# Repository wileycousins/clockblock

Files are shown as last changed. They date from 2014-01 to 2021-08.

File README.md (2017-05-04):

# clockblock

clockblock

An LED clock in a block of wood. This repository contains the electronics design files and firmware source code.

## firmware

Firmware is written in C++ and compiled in GCC 4.6.2 with AVR modifications. If you're using a Mac, install [CrossPack for AVR 2013-02-12](http://www.obdev.at/products/crosspack/index.html) for all the necessary tools. Otherwise, do some Googling.

The clockblock uses an ATTiny167 with 16KB of flash and 512B of RAM. At compilation, the application takes about 6KB of program and 30B of RAM. Currently firmware must be flashed onto the board with an ISP, but hardware supports USB bootloading*. An Arduino-compatible bootloader is in the works.

*v1.0 hardware has a trace that must be cut and replaced with a capacitor for this to work. See [issue #6](https://github.com/wileycousins/clockblock/issues/6).

## hardware

The PCBs are designed in [KiCad](https://launchpad.net/kicad). There are gerber files in the repo, but your best bet is to generate them yourself from KiCad. Components are from [these libraries](https://github.com/mcous/kicad-lib), but you shouldn't have to install them to view the schematic and board files if you don't want to.

The boards are almost entirely surface mount, so solder-paste and a reflow tool of some sort (hot-air gun, toaster, hot-plate) are recommended. If anyone manages this with just an iron, I'd love to see pictures, because that's awesome. Shameless self promotion: I know about this pretty good [toaster oven control board for solder reflow](https://github.com/mcous/reflow).

[clockblock-image]: https://cloud.githubusercontent.com/assets/2963448/25712589/0aaff954-30c0-11e7-9aac-50ed0ab61022.jpg

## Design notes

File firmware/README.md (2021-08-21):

# firmware

## setup

### Arduino (one time setup)
Make sure you have `Arduino.app` installed in the usual place.

You'll need a special Board for Arduino. Add `http://drazzy.com/package_drazzy.com_index.json` to the `Additional Boards Manager URLs: ` in the Preferences in Arduino.

You'll need to setup your Arduino Uno for `ArduinoISP`. Select `ArduinoISP` from the `File > Examples > ArduinoISP`. Upload this sketch to the Uno.

Now wire the AVR ISP board into the appropriate pins on the Uno. Also, very important! Put a 10µf capacitor between ground and reset. Make sure to put the ground of the capacitor in the ground (the short leg).

### .env

This is being tracked in git which is debatable, but we should have the same env at this point and nothing sensitive is in here. But this is how the .env was made just for reference:

```bash
# Add the Arduino avr stuff to your path
echo "export PATH=/Applications/Arduino.app/Contents/Java/hardware/tools/avr/bin:\$PATH" >> .env

# make sure Arduino Uno is plugged in and setup for ArduinoISP
echo "export SERIAL_PORT=\$(ls /dev/cu.usb*)" >> .env
```

Follow dmg package install steps

## build

```bash
source .env
cd src
make
```

## flash

```bash
# make sure you env is all good to go
source ../.env
make test
# assuming the test comes back all good.
make flash
```

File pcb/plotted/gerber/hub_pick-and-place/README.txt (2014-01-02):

clockblock v1.0 hub and usb boards
Prepared by Michael Cousins
michael@wileycousins.com
(281) 210-6984

This panel consists of the two boards in our product with surface mount components. We will handle de-panellization. 

Requested specs:
  * ENIG finish
  * 0.062", 1 oz copper
  * White soldermask
  * Silkscreen on both sides
  * Red silkscreen if possible, otherwise black silkscreen

File summary:
Gerbers:
  * clockblock-hub-B_Cu.gbl      - bottom copper
  * clockblock-hub-B_Mask.gbs    - botton soldermask
  * clockblock-hub-B_SilkS.gbo   - bottom silkscreen
  * clockblock-hub-Edge_Cuts.gbr - board outline
  * clockblock-hub-F_Cu.gtl      - top copper
  * clockblock-hub-F_Mask.gts    - top soldermask
  * clockblock-hub-F_Paste.gtp   - top solderpaste
  * clockblock-hub-F_SilkS.gto   - top silkscreen
Excellon drill files (inches, 2:4 precision, no zero suppression):
  * clockblock-hub-NPTH.drl - drill file for non-plated though holes
  * clockblock-hub.drl      - drill file for plated through holes

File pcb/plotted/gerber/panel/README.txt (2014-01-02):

clockblock v0.2 arms panel
Prepared by Michael Cousins
michael@wileycousins.com

This panel is 4.8" x 4.2" and divided by v-scoring into 48 0.6" x 0.7" boards. The panel should have 7 evenly-spaced vertical v-scores and 5 evenly-spaced horizontal v-scores. Score lines are indicated in the board outline file.

Requested specs:
  * ENIG finish
  * 0.062", 1 oz copper
  * White soldermask
  * Silkscreen on top, none on bottom
  * Red silkscreen if possible, otherwise black silkscreen

File summary:
Gerbers:
  * clockblock-arms-B_Cu.gbl      - bottom copper
  * clockblock-arms-B_Mask.gbs    - botton soldermask
  * clockblock-arms-Edge_Cuts.gbr - board outline and scoring indication
  * clockblock-arms-F_Cu.gtl      - top copper
  * clockblock-arms-F_Mask.gts    - top soldermask
  * clockblock-arms-F_SilkS.gto   - top silkscreen
Excellon drill files (inches, 2:4 precision, no zero suppression):
  * clockblock-arms.drl - drill file for plated through holes

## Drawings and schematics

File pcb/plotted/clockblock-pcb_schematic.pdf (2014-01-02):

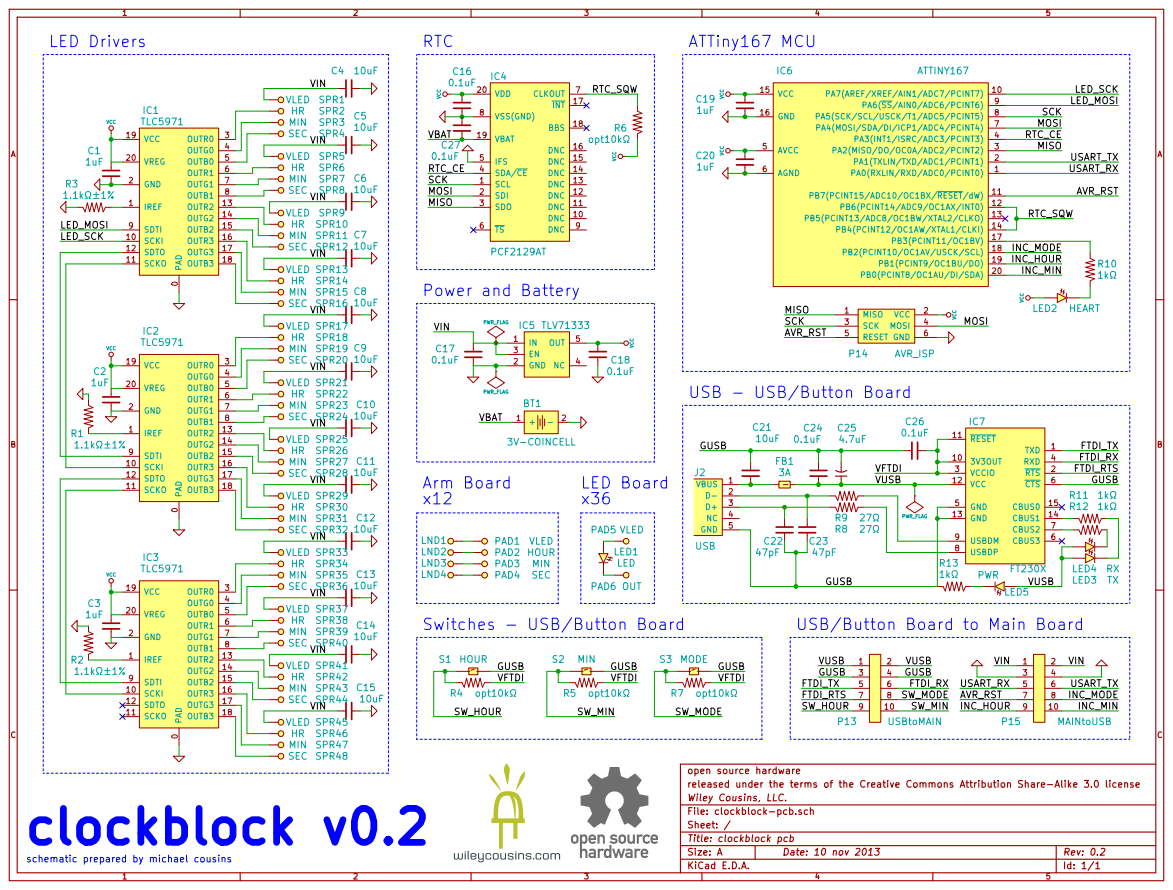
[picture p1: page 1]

SEC SPR8 VLED SPR9 HR SPR10 MIN SPR11
10uF VIN

LED_SCK

SEC SPR12 VLED SPR13 HR SPR14 MIN SPR15

INC_MODE
INC_HOUR

SEC SPR20 VLED SPR21 HR SPR22 MIN SPR23

USB - USB/Button Board

SEC SPR24 VLED SPR25 HR SPR26 MIN SPR27

SEC SPR28 VLED SPR29 HR SPR30 MIN SPR31

SEC SPR32 VLED SPR33 HR SPR34 MIN SPR35

SEC SPR36 VLED SPR37 HR SPR38 MIN SPR39

USB/Button Board to Main Board

SEC SPR40 VLED SPR41 HR SPR42 MIN SPR43

SEC SPR44 VLED SPR45 HR SPR46 MIN SPR47

open source hardware
released under the terms of the Creative Commons Attribution Share-Alike 3.0 license
Wiley Cousins, LLC.
File: clockblock-pcb.sch
Sheet: /
Title: clockblock pcb

schematic prepared by michael cousins

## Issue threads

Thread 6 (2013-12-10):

FTDI RTS signal should go through a capacitor

mcous, 2013-12-10:
Currently, it's hooked straight to the AVR's reset line, which pulls the AVR into a reset loop whenever a USB serial connection is open.

Workaround is to cut the trace and place a 0.1 uF capacitor over the cut.

Fix circuit for 1.1

Closed 2023-09-13.

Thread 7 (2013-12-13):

Tx and Rx silkscreens are backwards

mcous, 2013-12-13:
Tx and Rx LEDs are labelled backwards in the schematic and on the boards. Fix for next revision if sticking with the FTDI 230X.

Closed 2023-09-13.

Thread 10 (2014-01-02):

Replace individual LED boards with 3 LED arms

mcous, 2014-01-02:
Move back to the v0.1 structure of 12 arms rather than 12 landing boards and 36 LED boards.

Closed 2023-09-13.

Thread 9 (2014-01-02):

Rework optiboot to work on ATTiny167

mcous, 2014-01-02:
Will probably need to get a good RC calibration procedure written, too, for not super-slow upload speeds.

Closed 2023-09-13.

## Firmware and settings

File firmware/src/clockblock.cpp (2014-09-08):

// clockblock
// Copyright 2013 by Wiley Cousins, LLC.
// shared under the terms of the MIT License
//
// file: clockblock.cpp
// description: application file for the clockblock

// ************************************
// AVR includes necessary for this file
// ************************************
//#include <util/atomic.h>
#include <util/delay.h>

// ********************
// application includes
// ********************
#include "clockblock.h"


// **************************
// INTERRUPT SERVICE ROUTINES
// **************************
// frame counter ISR (timer 0 is clocked by the RTC)
ISR(TIMER0_OVF_vect) {
  tick = true;
}

// switch poller / debouncer / timer
ISR(INPUT_TIMER_vect, ISR_NOBLOCK) {
  // disable interrupt
  buttons.disableTimer();
  // handle the polling
  buttons.handleTimer();
  // re-enable the interrupt
  buttons.enableTimer();
}

// ***********
// application
// ***********
// main
int main(void) {
  // debugging
  #ifdef DEBUG
  // set up the heartbeat led
  DDRB |= (1<<3);
  PORTB |= (1<<3);

  // examine the last reset
  // watchdog reset - blink LED 4 times
  if (MCUSR & (1<<WDRF)) {
    for (uint8_t i=0; i<4; i++) {
      beatHeart();
      _delay_ms(250);
      beatHeart();
      _delay_ms(250);
    }
  }
  else if (MCUSR & (1<<BORF)) {
    for (uint8_t i=0; i<3; i++) {
      beatHeart();
      _delay_ms(250);
      beatHeart();
      _delay_ms(250);
    }
  }
  else if (MCUSR & (1<<EXTRF)) {
    for (uint8_t i=0; i<2; i++) {
      beatHeart();
      _delay_ms(250);
      beatHeart();
      _delay_ms(250);
    }
  }
  else if (MCUSR & (1<<PORF)) {
    for (uint8_t i=0; i<1; i++) {
      beatHeart();
      _delay_ms(250);
      beatHeart();
      _delay_ms(250);
    }
  }
  // clear the flags
  MCUSR = 0;
  #endif


  // delay for a few ms to allow the RTC to take its initial temp measurement
  _delay_ms(1000);

  // begin setup - disable interrupts
  cli();

  // take care of unused pins
  initUnusedPins();

  // give those ISR volatile vairables some values
  tick = false;

  // application variables
  // time vector - { seconds, minutes, hours}
  uint8_t tm[3] = {0, 0, 12};
  // animation frame
  uint8_t fr = 0;
  // arms leds
  uint16_t dots[DISPLAY_NUM_DOTS];

  // initialize the LED driver
  // DO THIS BEFORE INITIALIZING RTC (to ensure proper SPI functionality for the RTC)
  tlc.init();
  // set the TLC to autorepeat the pattern and to reset the GS counter whenever new data is latched in
  tlc.setFC(TLC5971_DSPRPT);
  // set brightness to about 50% (to account for bad wall warts)
  tlc.setBC(60);

  // initialize the RTC
  rtc.init();
  // enable a 8192 Hz squarewave output on clock input pin
  rtc.setSquareWave(PCF2129AT_CLKOUT_8_kHz);

  // check the oscillator stop flag on the RTC and give it a new time if necessary
  if (rtc.hasLostTime()) {
    rtc.setTime(tm, PCF2129AT_AM);
  }
  // else get the good time from the RTC
  else {
    rtc.getTime(tm);
  }

  // initialize the ticker
  initTicker();

  // set the display mode
  leds.setMode(DISPLAY_MODE_BLEND);

  // enable inputs
  buttons.init();

  // end setup - enable interrupts
  sei();

  // get lost
  for (;;) {
    // take care of any switch presses
    uint8_t buttonState = 0;
    if (buttons.getPress(&buttonState)) {
      handleButtonPress(buttonState, tm);
    }

    // update the arms on a tick
    if (tick) {
      // clear the flag
      tick = false;
      // get the time
      if (++fr >= 32) {
        // beat the heart every second
        beatHeart();
        fr = 0;
        rtc.getTime(tm);
      }
      // update the clock arms
      updateArms(tm, fr, dots);
    }
  }

  // one day we might get the answer
  return 42;
}


// update the clock arms
// dots array structure: { hr0, mn0, sc0, hr1, mn1, sc1, ... , hr11, mn11, sc11 }
void updateArms(uint8_t *tm, uint8_t frame, uint16_t *dots) {
  // get the display
  leds.getDisplay(tm, frame, dots);
  // send to the LED driver
  tlc.setGS(dots);
}


// initialize unused pins as inputs with pullups enabled
void initUnusedPins(void) {
  // PORTB
  DDRB &= ~UNUSED_PORTB_MASK;
  PORTB |= UNUSED_PORTB_MASK;
  // PORTA
  DDRA &= ~UNUSED_PORTA_MASK;
  PORTA |= UNUSED_PORTA_MASK;
}


// button handling logic
void handleButtonPress(uint8_t state, uint8_t *tm) {
  // if a time set switch was pressed
  if ( state & (INPUT_HOUR | INPUT_MIN)) {
    // temporary time register to avoid messing up the seconds LEDs
    uint8_t set[3];
    // get the real time
    rtc.getTime(set);
    // if hour switch, increment the hours by 1
    if (state & INPUT_HOUR) {
      if (++set[2] > 12) {
        set[2] -= 12;
      }
    }
    // if minute switch, increment minutes
    if (state & INPUT_MIN) {
      if (++set[1] > 59) {
        set[1] -= 60;
      }
    }
    // tell the clock and then the app
    rtc.setTime(set, PCF2129AT_AM);
    tm[2] = set[2];
    tm[1] = set[1];
  }
  // if mode switch, increment mode
  if (state & INPUT_MODE) {
    uint8_t m = leds.getMode();
    m = (m < DISPLAY_NUM_MODES-1) ? m+1 : 0;
    leds.setMode(m);
  }
}


void beatHeart(void) {
  #ifdef DEBUG
  PINB |= (1<<3);
  #endif
}


void initTicker(void) {
  // set timer 0 to run normally with no prescaler
  TCCR0A = 0;
  TCCR0B = (1<<CS00);
  // set timer 0 to clock from the RTC squarewave
  ASSR = (1<<EXCLK);
  // set timer 0 to clock asynchronously and reload the counter
  ASSR |= (1<<AS0);
  TCNT0 = 0;
  // enable timer 0 overflow interrupt
  TIMSK0 = (1<<TOIE0);
}

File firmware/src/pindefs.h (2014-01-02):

// clockblock
// Copyright 2013 by Wiley Cousins, LLC.
// shared under the terms of the MIT License
//
// file: pindefs.h
// description: port and pin definitions

#ifndef CLOCKBLOCK_PINDEFS_H
#define CLOCKBLOCK_PINDEFS_H

// include for AVR register addresses
#include <avr/io.h>

// DDR and PIN from port register macros
#define DDR(port) (*(&port-1))
#define PIN(port) (*(&port-2))

// PIN DEFINES FOR V0.1
// SPI
#define SPI_MOSI_DDR  DDRA
#define SPI_MOSI_PIN  4
#define SPI_SCK_DDR   DDRA
#define SPI_SCK_PIN   5

// RTC
// RTC pins
#define RTC_CS_PORT   PORTA
#define RTC_CS_PIN    3
//#define RTC_RST_PORT  PORTC
//#define RTC_RST_PIN   3
#define RTC_SQW_PORT  PORTB
#define RTC_SQW_PIN   6
// avr external interrupt
#define RTC_EXT_INT       0
#define RTC_EXT_INT_vect  INT0_vect

// TLC5971
#define TLC_N          3
#define TLC_N_LEDS     (TLC_N * 12)
#define TLC_MOSI_PORT  PORTA
#define TLC_MOSI_PIN   6
#define TLC_SCK_PORT   PORTA
#define TLC_SCK_PIN    7

// switches
// switch pins
#define INPUT_PORT  PORTB
#define INPUT_MODE  (1<<2)
#define INPUT_HOUR  (1<<1)
#define INPUT_MIN   (1<<0)
#define INPUT_MASK  (INPUT_MODE | INPUT_HOUR | INPUT_MIN)

// switch interrupts
#define INPUT_PCMSK       PCMSK1
#define INPUT_PCICR       PCICR
#define INPUT_PCIE        (1<<PCIE1)
#define INPUT_PCINT_vect  PCINT1_vect
// switch debounce timer
#define INPUT_TIMER_vect  TIMER1_COMPA_vect

// unused pins to be pulled up internally
#define UNUSED_PORTB_MASK  ( (1<<6) | (1<<5) | (1<<4) | (1<<2) | (1<<1) | (1<<0) )
#define UNUSED_PORTA_MASK  ( (1<<1) | (1<<0) )

#endif

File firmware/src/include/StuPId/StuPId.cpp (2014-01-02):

// clockblock
// Copyright 2013 by Wiley Cousins, LLC.
// shared under the terms of the MIT License
//
// file: StuPId.cpp
// description: stupid little SPI master class

// avr include
#include "avr/io.h"

// pindefs from main app with DDR and pin defines
#include "pindefs.h"
// check that necessary pins and ports are defined
#ifndef SPI_MOSI_DDR
#error "SPI_MOSI_DDR is not defined; please define in pindefs.h"
#endif
#ifndef SPI_MOSI_PIN
#error "SPI_MOSI_PIN is not defined; please define in pindefs.h"
#endif
#ifndef SPI_SCK_DDR
#error "SPI_SCK_DDR is not defined; please define in pindefs.h"
#endif
#ifndef SPI_SCK_PIN
#error "SPI_SCK_PIN is not defined; please define in pindefs.h"
#endif

// class definition
#include "StuPId.h"

// constructor takes in data direction registers for MOSI and SCK
StuPId::StuPId() {
  /*
  // save mosi pin
  ddrMosi = mosiDdr;
  pinMosi = mosiPin;
  // save sck pin
  ddrSck = sckDdr;
  pinSck = sckPin;
  */
}

// set pin directions and enable SPI
void StuPId::enable() {
  SPI_MOSI_DDR |= (1 << SPI_MOSI_PIN);
  SPI_SCK_DDR |= (1 <<SPI_SCK_PIN);

  // set the SPI enable bit and the master mode bit
  SPCR |= ( (1 << SPE) | (1 << MSTR) );
  enabled = true;
}

// diable SPI
void StuPId::disable() {
  SPCR &= ~(1 << SPE);
  enabled = false;
}

// returns if enabled
bool StuPId::isEnabled() {
  if (SPCR & (1<<SPE)) {
    return true;
  }
  else {
    return false;
  }
}

// set data mode, overloaded to either take modes 0-3 or the polarity phase pair
void StuPId::setDataMode(uint8_t mode) {
  if (mode < 4) {
    SPCR = ( (SPCR & ~((1<<CPHA)|(1<<CPOL))) | (mode << CPHA) );
  }
}

void StuPId::setDataMode(uint8_t pol, uint8_t pha) {
  if (pol>1) {
    pol = 1;
  }
  if (pha>1) {
    pha = 1;
  }
  setDataMode( (pol<<1) | pha );
}

// set the data direction (MSB_FIRST or LSB_FIRST)
void StuPId::setDataOrder(uint8_t order) {
  if (order == SPI_MSB_FIRST || order == SPI_LSB_FIRST) {
    SPCR = ( (SPCR & ~(SPI_LSB_FIRST)) | order );
  }
}

// set the interface speed
// takes in the clock divider and whether or not to run at double speed
void StuPId::setDataRate(uint8_t divide, uint8_t dbl) {
  if (divide <= SPI_DIV_128) {
    SPCR = ( (SPCR & ~(SPI_DIV_128)) | divide);
  }
  if (dbl <= SPI_SPEED_DOUBLE) {
    SPSR = ( (SPSR & ~(SPI_SPEED_DOUBLE)) | dbl );
  }
}

// transfer data
// synchronous protocol, so it writes the parameter and returns what it recieves
uint8_t StuPId::transfer(uint8_t data) {
  if (enabled) {
    SPDR = data;
    while(!(SPSR & (1<<SPIF)));
    return SPDR;
  }
  else {
    return 0;
  }
}

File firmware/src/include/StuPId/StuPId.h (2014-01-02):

// clockblock
// Copyright 2013 by Wiley Cousins, LLC.
// shared under the terms of the MIT License
//
// file: StuPId.h
// description: header for stupid little SPI master class

#ifndef LIB_STUPID_H
#define LIB_STUPID_H

#include <stdint.h>

// data order defines
#define SPI_MSB_FIRST 0
#define SPI_LSB_FIRST (1<<5)

// clock divider defines
#define SPI_DIV_4    0
#define SPI_DIV_16   1
#define SPI_DIV_64   2
#define SPI_DIV_128  3

#define SPI_SPEED_NORMAL 0
#define SPI_SPEED_DOUBLE 1


class StuPId {
public:
  // constructor takes in data direction registers for MOSI and SCK
  StuPId();
  // set pin directions and enable SPI
  void enable();
  // diable SPI
  void disable();
  // is enabled bool
  bool isEnabled();
  // set data mode, overloaded to either take modes 0-3 or the polaity phase pair
  void setDataMode(uint8_t mode);
  void setDataMode(uint8_t pol, uint8_t pha);
  // set the data direction (MSB_FIRST or LSB_FIRST)
  void setDataOrder(uint8_t order);
  // set the interface speed
  // takes in the clock divider and whether or not to run at double speed
  void setDataRate(uint8_t divide, uint8_t dbl);
  // transfer data
  // synchronous protocol, so it writes the parameter and returns what it recieves
  uint8_t transfer(uint8_t data);

private:
  bool enabled;
  // volatile uint8_t *ddrMosi;
  // uint8_t pinMosi;
  // volatile uint8_t *ddrSck;
  // uint8_t pinSck;
};

#endif

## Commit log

2013-09-23 added kicad project for electronics
2013-09-24 got a good start to the v0.1 schematic
    [clockblock-pcb.kicad_pcb, clockblock-pcb.sch]
2013-09-24 fixed incorrect LED polarity, added arm headers, and added a backup coincell for the RTC
    [clockblock-pcb.sch]
2013-09-24 annotated schematic and fixed up a component pin type error
    [clockblock-pcb.sch]
2013-09-24 updated schematic plot to latest
2013-09-24 component footprints done, moving onto layout
    [clockblock-pcb.sch]
2013-09-25 time to eat dinner
    [clockblock-pcb.kicad_pcb]
2013-09-25 most of the hub placement done. shooting for a board sent to fab tomorrow
    [clockblock-pcb.kicad_pcb, clockblock-pcb.sch]
2013-09-26 board layout done. double checking then sending to fab
    [clockblock-pcb.kicad_pcb, clockblock-pcb.sch]
2013-09-26 added extra header footprint on arm for positioning options
    [clockblock-pcb.kicad_pcb]
2013-09-26 safety commit before fucking with shit to generate fab files
    [clockblock-pcb.kicad_pcb]
2013-09-26 fabrication files
    [clockblock-hub-B_Cu.gbl, clockblock-hub-B_Mask.gbs, clockblock-hub-B_SilkS.gbo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]
2013-09-26 updated schematic plot to version sent to fabrication
2013-09-28 SPI helper functions set up
2013-09-28 code compiles... uploading to arduino
2013-09-28 the arduino SPI library is giving me issues when trying to use my DS3234 class. WHO WOULD'VE THUNK IT
2013-09-28 writing a stupid SPI library
2013-09-28 new spi library seems to work
2013-09-30 adding files for TLC5971 led driver class
2013-10-02 moved to a new breadboard. working on LED algorithms
2013-10-02 actually got the clock ticking and lighting the LEDs properly
2013-10-03 working with 2 drivers for 32 of 36 leds
2013-10-03 basic TLC5940 lib can't handle three drivers. other than that everything works great.
2013-10-08 corrected fab files with fixed drill file and fixed soldermask
    [clockblock-hub-B_Cu.gbl, clockblock-hub-B_Mask.gbs, clockblock-hub-B_SilkS.gbo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]
2013-10-08 added _autosave files from pcbnew to gitignore
2013-10-08 gitignore modified to ignore pcbnew autosaves
2013-10-08 fixed soldermask and drill fab files and sent to oshpark
    [clockblock-hub-B_Cu.gbl, clockblock-hub-B_Mask.gbs, clockblock-hub-B_SilkS.gbo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]
2013-10-10 new TLC5940 driver works a lot better. got a full clock running
2013-10-11 corrected deprecated <avr/delay.h> include to <util/delay.h>
    [DS3234.cpp]
2013-10-11 trying to introduce millisecond tracking and smoothing looks cool, but is introducing some harmonics
2013-10-17 really basic increment hours and minutes with switches going
2013-10-17 fixed up the ISRs to remove beating effect from TLC serial clock
    [clockblock.cpp]
2013-10-17 holding down a switch puts the clock into and out of the set mode effect
2013-10-18 pin interrupts set up. fixing up the app
    [clockblock.cpp]
2013-10-18 can now change modes and time with the buttons
2013-10-22 pins replaced with defines from pindefs
    [clockblock.cpp]
2013-10-22 defined the framerate and put it in the code
2013-10-22 added in defines for v0.1 pcb
2013-10-23 gonna see if i like a class for handling the buttons
2013-10-23 moved button handling to separate class
2013-10-23 flipped the way button states are reported to the app
    [clockblock.cpp]
2013-10-23 changed button timer counter to 16 bit int and cleaned up comments
2013-10-23 moved the button handling out of the main
2013-10-23 matching up breadboard and pcb defines
2013-10-23 test program to ensure TLC5971 driver works on PCB
2013-10-23 added appropriate fuse bit values to the makefile
2013-10-29 TLC5971 confirmed working on pcb
2013-10-29 getting ready to put this on the v0.1 board
2013-11-05 moving on to v0.2 schematic
    [clockblock-pcb.sch]
2013-11-07 predinner commit
    [clockblock-pcb.sch]
2013-11-07 first pass at v0.2 schematic done
    [clockblock-pcb.sch]
2013-11-07 just kidding, this is better
    [clockblock-pcb.sch]
2013-11-07 adding meaningless embelishments
    [clockblock-pcb.sch]
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2013-11-07 attempting to fix schematic images
    [clockblock-pcb.sch]
2013-11-07 busy work fixing minor perfectionist details
    [clockblock-pcb.sch]
2013-11-07 fixing ERC in progress
    [clockblock-pcb.sch]
2013-11-07 appropriate power flags added
    [clockblock-pcb.sch]
2013-11-07 putting LEDs on correct voltage net
    [clockblock-pcb.sch]
2013-11-07 putting switches on correct voltage net
    [clockblock-pcb.sch]
2013-11-07 going to bed
    [clockblock-pcb.sch]
2013-11-07 got started on the layout and footprint selection
    [clockblock-pcb.kicad_pcb, clockblock-pcb.sch]
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2013-11-07 trying out spring connections for arms
    [clockblock-pcb.sch]
2013-11-07 initial footprint selection done
    [clockblock-pcb.sch]
2013-11-08 continuing work on schematic and layout
    [clockblock-pcb.kicad_pcb, clockblock-pcb.sch]
2013-11-08 putting part numbers in the schematic
    [clockblock-pcb.sch]
2013-11-08 going to get dinner. need to finish layout
    [clockblock-pcb.sch]
2013-11-08 did some layout stuff. time for bed
    [clockblock-pcb.kicad_pcb, clockblock-pcb.sch]
2013-11-08 safety commit
    [clockblock-pcb.sch]
2013-11-08 example layout for usb/button board
    [clockblock-pcb.kicad_pcb, clockblock-pcb.sch]
2013-11-09 traces laid from drivers to LEDs
    [clockblock-pcb.kicad_pcb, clockblock-pcb.sch]
2013-11-09 led driver serial connections made
    [clockblock-pcb.kicad_pcb]
2013-11-09 hub done other than silkscreen
    [clockblock-pcb.kicad_pcb, clockblock-pcb.sch]
2013-11-09 pretty much done, but i gotta call it a night to prevent mistakes;
    [clockblock-pcb.kicad_pcb]
2013-11-09 reworked the usb button board into something more feasible
    [clockblock-pcb.kicad_pcb, clockblock-pcb.sch]
2013-11-09 I think I might have everything we need laid out
    [clockblock-pcb.kicad_pcb]
2013-11-09 nevermind, we have 36 LEDs. problem solved
    [clockblock-pcb.kicad_pcb]
2013-11-10 getting ready to generate new fab files
    [clockblock-hub-B_Cu.gbl, clockblock-hub-B_Mask.gbs, clockblock-hub-B_SilkS.gbo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]
2013-11-10 changing mousebites to pth
    [clockblock-pcb.kicad_pcb]
2013-11-10 fixed missing pad for individual LED board
    [clockblock-pcb.kicad_pcb]
2013-11-10 added pick and place layout
    [clockblock-pcb.kicad_pcb]
2013-11-10 fabrication work
    [clockblock-arms-B_Cu.gbl, clockblock-arms-B_Mask.gbs, clockblock-arms-Edge_Cuts.gbr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]
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2013-12-03 updating silkscreen for production
    [clockblock-pcb.kicad_pcb]
2013-12-03 fab work for 50 run
    [clockblock-pcb.kicad_pcb]
2013-12-04 power on vs reset anomolies still a problem. branching
    [PCF2129AT.cpp, clockblock.cpp]
2013-12-04 rtc operating and drivers initialized with no problems
    [clockblock.cpp, pindefs.h]
2013-12-04 everything seems to be alright. branching to write switch polling
2013-12-04 restoring interrupt based switches leads to some bug
    [clockblock.cpp, pindefs.h]
2013-12-06 switched rtc strobe to asyncronous timer rather than external interrupt
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2013-12-10 getting ready to try fixed point math again
    [clockblock.cpp]
2013-12-10 adding code to examine reset source
    [clockblock.cpp]
2013-12-10 new and exciting bug introduced
    [clockblock.cpp]
2013-12-10 error in the debug code but didn't fix program bug
    [clockblock.cpp]
2013-12-10 bug was that i'm an idiot
    [clockblock.cpp]
2013-12-11 adding overloaded brightnesss control method to TLC driver
2013-12-15 reverted to original math and found bug in switch code. fixed
    [clockblock.cpp]
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2014-01-02 modified to work better with subpar wallwarts and long cables
